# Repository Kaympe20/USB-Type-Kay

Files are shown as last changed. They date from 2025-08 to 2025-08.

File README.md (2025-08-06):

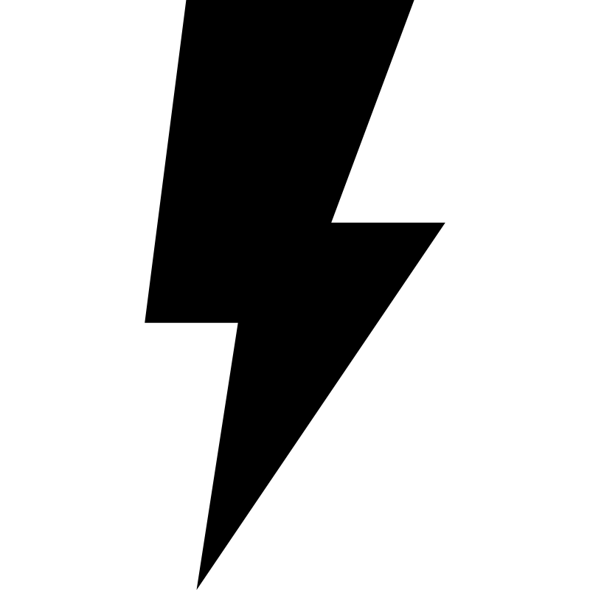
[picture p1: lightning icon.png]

# USB Type-Kay

<br>

A USB-A Hub powered by USB-C.

I made this powered USB Hub because I use a USB Hub at my desk, but not everything works correctly when it doesn't recieve all of the 500mA current. It would be much nicer if there was enough power such that each port could have the full power of a regular USB-A port.

## Pics











## CAD

The entire CAD workspace can be found on [Onshape](https://cad.onshape.com/documents/c7f694b62a224799f4cb962e/w/0d1c46c09d0047ca434a2fd4/e/c17be9d34015dc597f20f24c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)

## BOM

| Item | Quantity | Price | Price After Taxes + Shipping |
|---|---|---|---|
[Assembled PCB](https://github.com/Kaympe20/USB-Type-Kay/tree/main/production) | 1 | $28.01 | $80.56
[3D Printed Case](https://github.com/Kaympe20/Kaypaw96/blob/main/cad/Case.step) | 1 | $0 | $0
[M2 Hardware](https://www.amazon.com/QOOSIKICC-Assortment-Washers-Machine-Assorted/dp/B0DDY2L533) | N/a | $6.99 | $7.41
[M1 Hardware](https://www.amazon.com/Stainless-Assortment-Fasteners-Repairing-Electronics/dp/B09MS6KPN7) | N/a | $5.29 | $5.61

Total: $93.58

Here's the parts I selected in JLCPCB



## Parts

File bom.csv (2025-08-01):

Item | Quantity | Price | Price After Fees | Link
Assembled PCB | 1 | $28.01 | $80.56 | https://github.com/Kaympe20/USB-Type-Kay/tree/main/production
3D Printed Case | 1 | $0 | $0 | https://github.com/Kaympe20/Kaypaw96/blob/main/cad/Case.step
M2 Hardware | N/a | $6.99 | $7.41 | https://www.amazon.com/QOOSIKICC-Assortment-Washers-Machine-Assorted/dp/B0DDY2L533
M1 Hardware | N/a | $5.29 | $5.61 | https://www.amazon.com/Stainless-Assortment-Fasteners-Repairing-Electronics/dp/B09MS6KPN7

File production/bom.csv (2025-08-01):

Designator | Footprint | Quantity | Value | LCSC Part #
C1, C2, C3, C4, C5, C6, C7, C8 | C0603 | 8 | 10uF
D1, D2 | SOD-323_L1.8-W1.3-LS2.5-RD | 2 | D
J1 | USB_C_Receptacle_XKB_U262-16XN-4BVC11 | 1 | USB_C_Receptacle_USB2.0_14P
R1, R2 | R0402 | 2 | 5.1k
U1 | SOP-16_L10.0-W3.9-P1.27-LS6.0-BL | 1 | SL2.1A | C192893
USB1 | USB-A-TH_U-G-04WD-W-01 | 1 | U-G-04DD-W-01 | C98125
USB2, USB3, USB4, USB5 | USB-A-TH_C46407 | 4 | USB-AF-90-14.4X13.6-H7.0-DIP | C46407

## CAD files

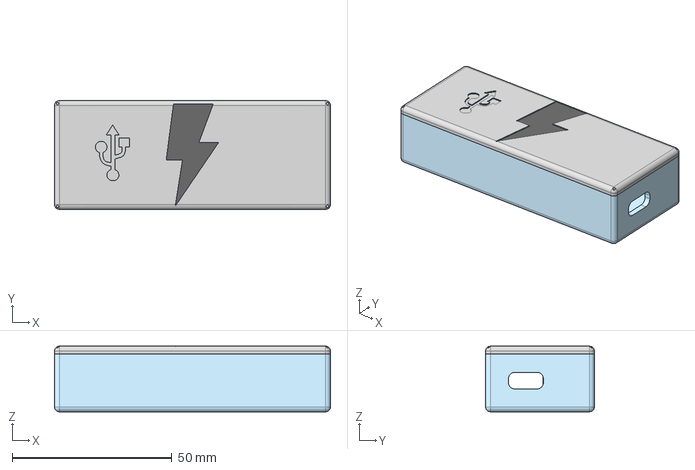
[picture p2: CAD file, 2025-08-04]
CAD/Case.step
86.3 x 34.0 x 20.5 mm

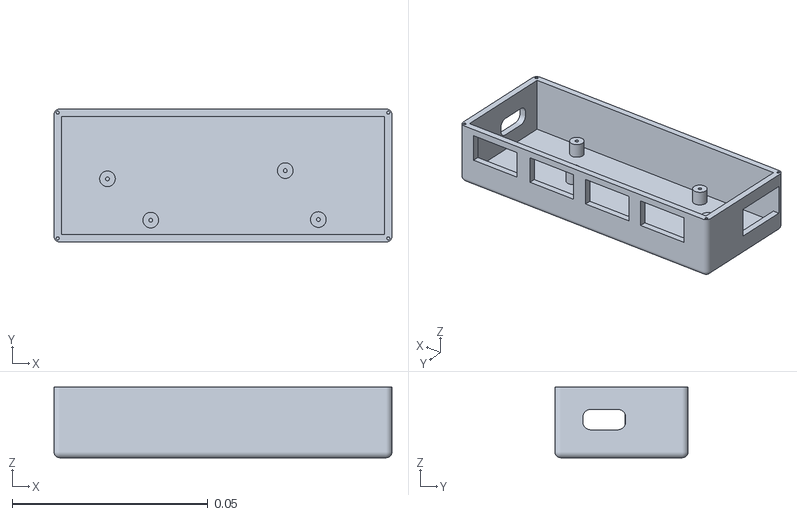
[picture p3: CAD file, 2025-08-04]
CAD/STL/Case - Bottom.stl
0.0863 x 0.034 x 0.018

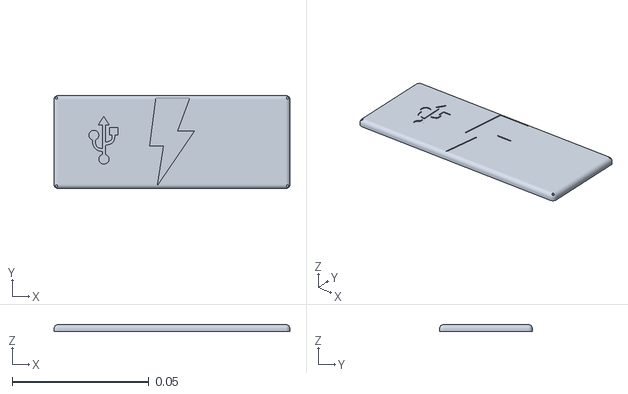
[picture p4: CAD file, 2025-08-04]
CAD/STL/Case - Top.stl
0.0863 x 0.034 x 0.0025

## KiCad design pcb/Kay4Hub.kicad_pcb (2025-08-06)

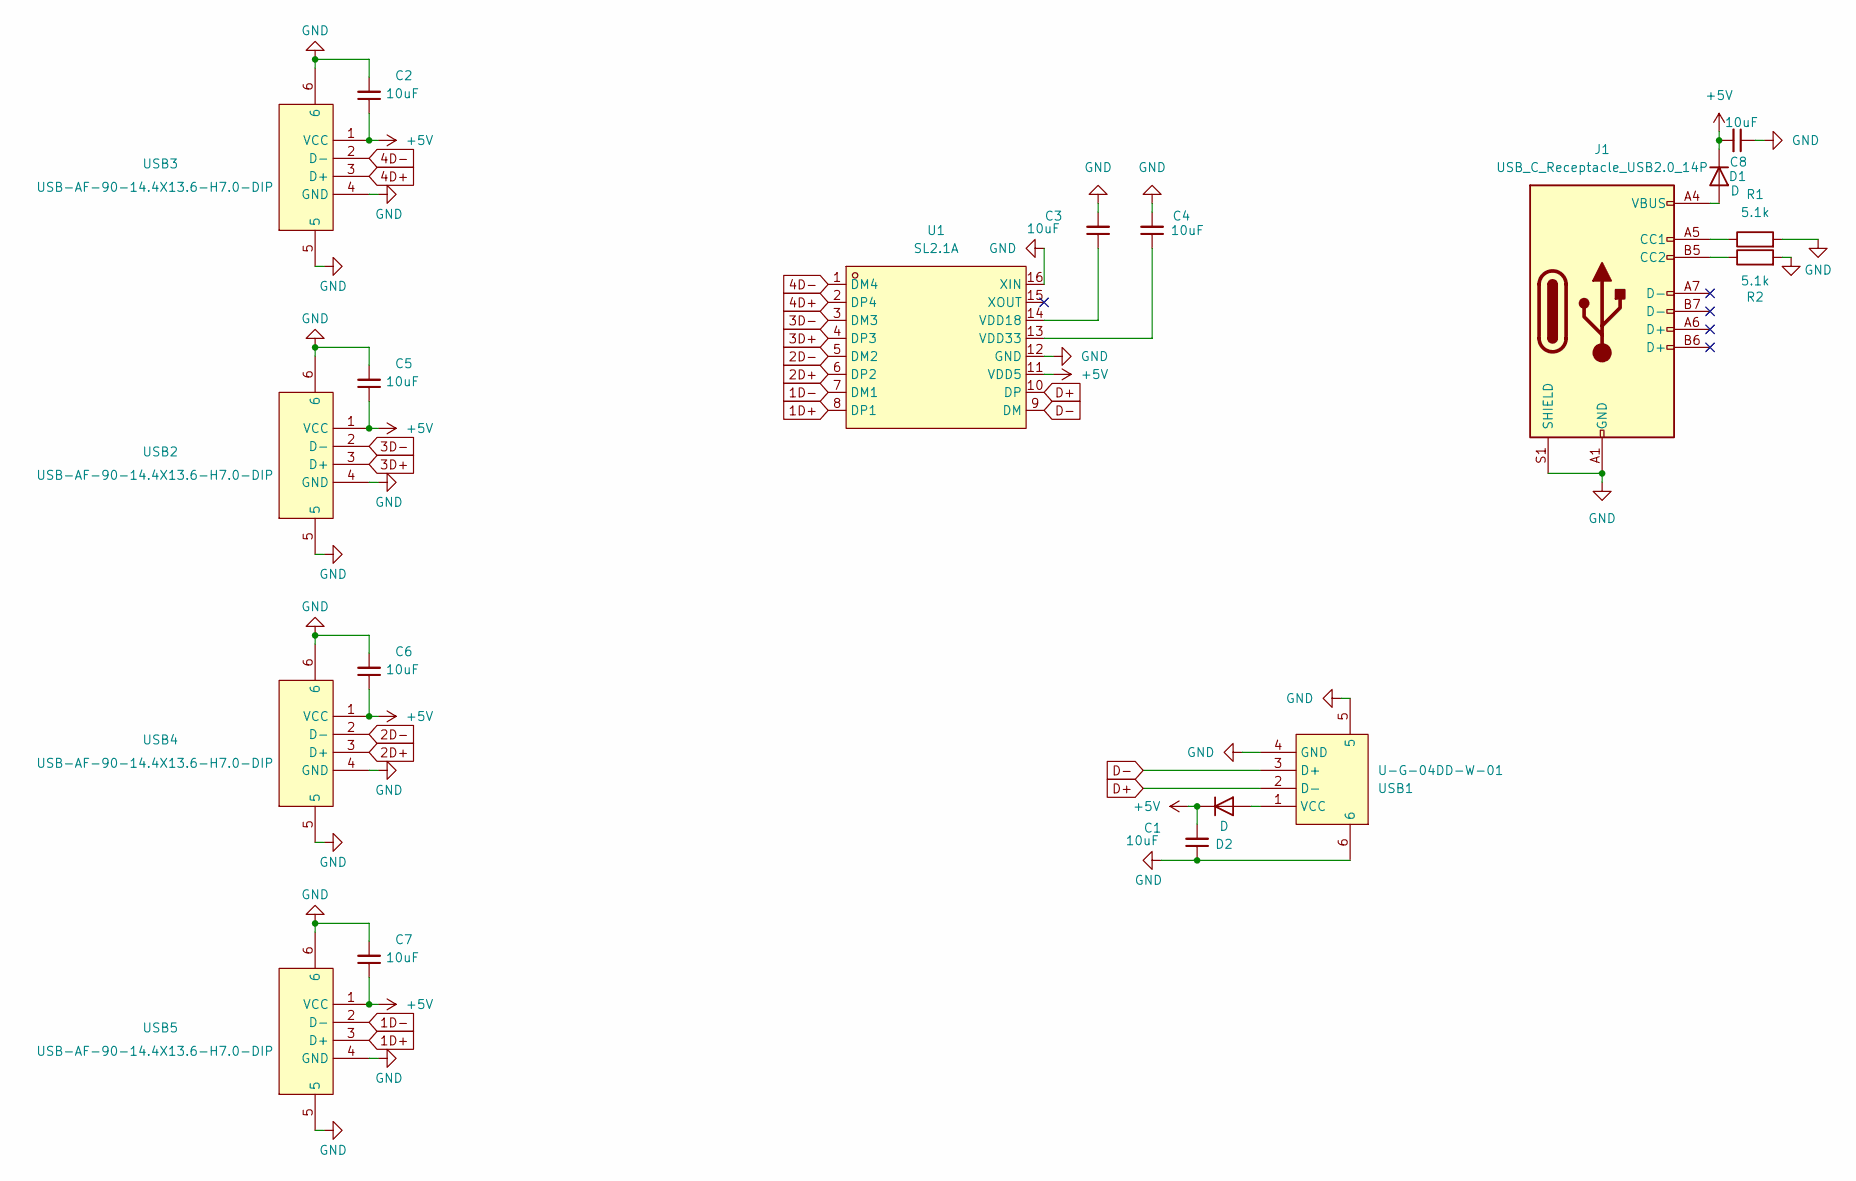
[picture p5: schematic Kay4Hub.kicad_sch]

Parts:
C1, C2, C3, C4, C5, C6, C7, C8: 10uF; C0603
D1, D2: D; SOD-323_L1.8-W1.3-LS2.5-RD
J1: USB_C_Receptacle_USB2.0_14P; USB_C_Receptacle_XKB_U262-16XN-4BVC11
R1, R2: 5.1k; R0402
U1: SL2.1A; SOP-16_L10.0-W3.9-P1.27-LS6.0-BL; LCSC Part C192893
USB1: U-G-04DD-W-01; USB-A-TH_U-G-04WD-W-01; LCSC Part C98125
USB2, USB3, USB4, USB5: USB-AF-90-14.4X13.6-H7.0-DIP; USB-A-TH_C46407; LCSC Part C46407

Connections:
1D+: U1.8 (DP1), USB5.3 (D+)
1D-: U1.7 (DM1), USB5.2 (D-)
2D+: U1.6 (DP2), USB4.3 (D+)
2D-: U1.5 (DM2), USB4.2 (D-)
3D+: U1.4 (DP3), USB2.3 (D+)
3D-: U1.3 (DM3), USB2.2 (D-)
4D+: U1.2 (DP4), USB3.3 (D+)
4D-: U1.1 (DM4), USB3.2 (D-)
+5V: C1.2, C2.1, C5.1, C6.1, C7.1, C8.2, D1.1 (K), D2.1 (K), U1.11 (VDD5), USB2.1 (VCC), USB3.1 (VCC), USB4.1 (VCC), USB5.1 (VCC)
D+: U1.10 (DP), USB1.2 (D-)
D-: U1.9 (DM), USB1.3 (D+)
GND: C1.1, C2.2, C3.2, C4.2, C5.2, C6.2, C7.2, C8.1, J1.A1 (GND), J1.A12 (GND), J1.B1 (GND), J1.B12 (GND), J1.S1 (SHIELD), R1.2, R2.2, U1.12 (GND), U1.16 (XIN), USB1.4 (GND), USB1.5, USB1.6, USB2.4 (GND), USB2.5, USB2.6, USB3.4 (GND), USB3.5, USB3.6, USB4.4 (GND), USB4.5, USB4.6, USB5.4 (GND), USB5.5, USB5.6
unnamed: D1.2 (A), J1.A4 (VBUS), J1.A9 (VBUS), J1.B4 (VBUS), J1.B9 (VBUS)
unnamed: D2.2 (A), USB1.1 (VCC)
unnamed: J1.A5 (CC1), R1.1
unnamed: J1.B5 (CC2), R2.1
unnamed: C3.1, U1.14 (VDD18)
unnamed: C4.1, U1.13 (VDD33)

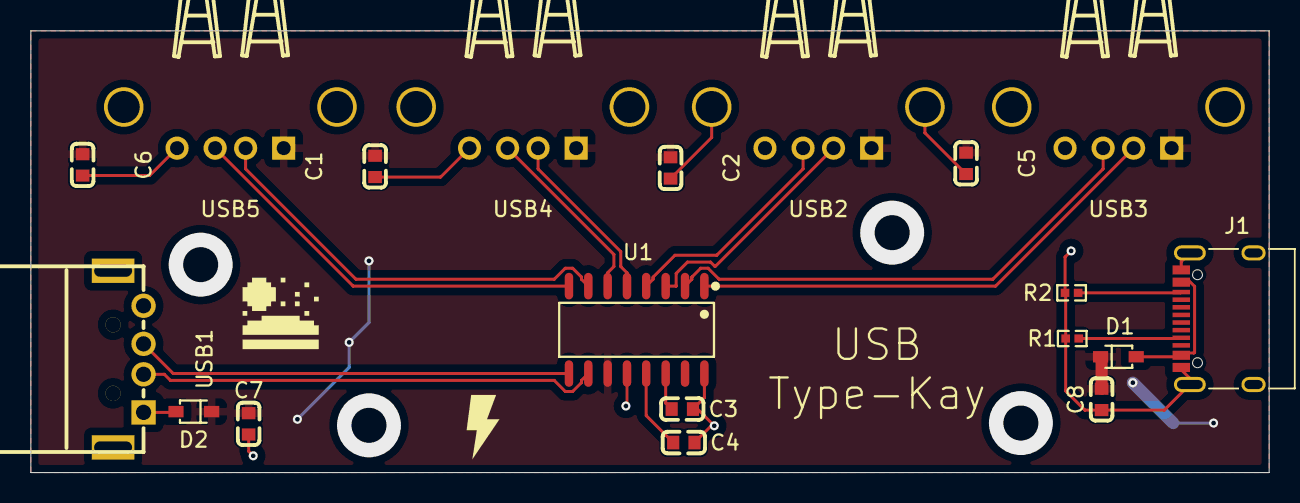
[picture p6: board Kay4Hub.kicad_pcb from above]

Board: 2 copper layers, 81.3 x 29.0 mm, 19 parts (0 on the bottom side), 18 nets.

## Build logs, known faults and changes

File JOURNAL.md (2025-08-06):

---
title: "USB Type-Kay"
author: "Kaympe20 aka @Kayla"
description: "A USB Hub powered with a USB-C Port"
created_at: "2025-7-31"
---

Total Time Spent: 8hr

## July 31, 2025

I started off looking at [this](https://jams.hackclub.com/batch/usb-hub) jam made by [@msw](https://github.com/maxwofford)



I wanted to to have each of the ports have more power though so that it didn't mess with devices meant for the full 500mA. I originally thought I would need USB-PD, but the 3A from legacy mode should be enough for 4 ports at 500mA each.

So I started making what I saw in the guide, with the difference that I added a USB-C recepticle and added diodes on both kinds of power supply so that it could still function as a passive USB hub when unplugged, without shorting out the port its in when the power is plugged in.



I went a little bit further and filled in all of the USB ports, as well as the rest of the connections. As far as I know, this is everything needed on the schematic side



Time Spent: 2hr

---

To get started with PCB design, I attached footprints to everything.



KiCAD did not include many of these and I had to use a tool called [`easyeda2kicad`](https://github.com/uPesy/easyeda2kicad.py) to download the footprints from LCSC and import them into KiCAD



I took a look at the 3D viewer and realized a lot of the 3d models were incorrect or missing, which means I have to go manually get them to work.



I then got to work on the actual PCB. I've heard USB requires the data plus and data minus pins to be differential, but KiCAD doesn't allow differential for things that don't end in N and P or + and - so I had to rename all of the nets, *one by one*.



I made a GND fill on the bottom and a 5V fill on top, mostly to be more efficient, and also to give the USB signaling less noise.

Here's what it looks like so far:



It looks a little bland so we should add in some nice customization



Here's what it looks like in 3D:



Time Spent: 2.5hr

---

I started preparing for case design by adding 4 M2 mounting holes.



I started with the bottom portion of the case with M1 screws to put it together.



And then I added the top.



Its wasn't really a looker so I gave it an aesthetic lightning bolt to signify its powered nature.



Here's what it looks like fully assembled





Time Spent: 3hr

---

## August 4, 2025

I fully connected the 5V



Time Spent: 15min

---

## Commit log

2025-07-31 Finish PCB
    [Kay4Hub.kicad_pcb, Kay4Hub.kicad_sch]
2025-08-01 Add all changes needed for Highway Submission
    [Case - Bottom.stl, Case - Top.stl, Case.step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]
2025-08-04 Update design with more stuff
    [Case - Bottom.stl, Case - Top.stl, Case.step]
2025-08-06 Connect those pins
    [Kay4Hub.kicad_pcb]
